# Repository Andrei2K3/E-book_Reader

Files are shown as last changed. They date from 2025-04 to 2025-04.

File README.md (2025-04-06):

# OpenBook Project - README

This repository contains the hardware, manufacturing, mechanical, and documentation files for **OpenBook**, a low-cost, open-source e-book reader built around the **ESP32-C6** microcontroller.

---

## Overview

The OpenBook is a low-power, open-source e-book reader designed around the ESP32-C6 microcontroller. Featuring Wi-Fi 6 and Bluetooth LE, it uses a large 7.5-inch e-paper display to achieve excellent readability and battery performance.

This document includes the system block diagram, hardware pinout, BOM, component links, design log, and licensing.

---

## System Block Diagram

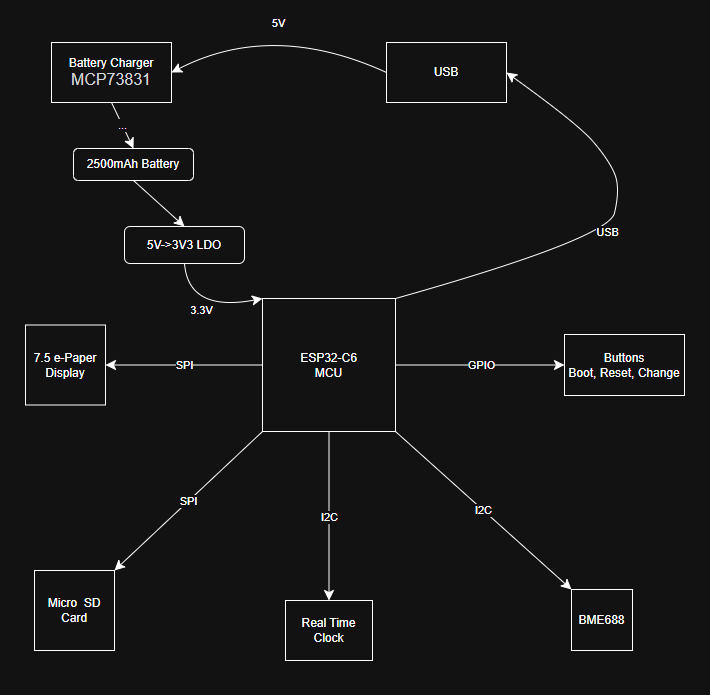
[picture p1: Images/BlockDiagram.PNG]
title


---

## Bill of Materials (BOM)

| Name of component | Device | Check Prices | DataSheet |
|---|---|---|---|
| U1 | W25Q512JVEIQ | https://www.snapeda.com/parts/W25Q512JVEIQ/Winbond+Electronics/view-part/?ref=eda | https://www.snapeda.com/parts/W25Q512JVEIQ/Winbond+Electronics/view-part/?ref=eda |
| U2 | ESP32-C6-WROOM-1-N8 | https://www.snapeda.com/parts/ESP32-C6-WROOM-1-N8/Espressif+Systems/view-part/?ref=eda | https://www.snapeda.com/parts/ESP32-C6-WROOM-1-N8/Espressif+Systems/view-part/?ref=eda |
| U3 | DS3231SN# | https://www.snapeda.com/parts/DS3231SN%23/Analog+Devices/view-part/?ref=eda | https://www.snapeda.com/parts/DS3231SN%23/Analog+Devices/view-part/?ref=eda |
| U4 | MAX17048G+T10 | https://www.snapeda.com/parts/MAX17048G+T10/Analog+Devices/view-part/?ref=eda | https://www.snapeda.com/parts/MAX17048G+T10/Analog+Devices/view-part/?ref=eda |
| U5 | ESP32_WROVER_SPARKFUN-IC-POWER_MCP73831 | https://eu.mouser.com/ProductDetail/Microchip-Technology/MCP73831T-2ACI-OT?qs=yUQqVecv4qvbBQBGbHx0Mw%3D%3Dcf | https://eu.mouser.com/ProductDetail/Microchip-Technology/MCP73831T-2ACI-OT?qs=yUQqVecv4qvbBQBGbHx0Mw%3D%3Dcf |
| BOOT_BUTTON | BUTTON_CUSYOMV1 | https://industry.panasonic.com/global/en/products/control/switch/light-touch/number/evqpuj02k | https://industry.panasonic.com/global/en/products/control/switch/light-touch/number/evqpuj02k |
| CHANGE_BUTTON | BUTTON_CUSYOMV1 | https://industry.panasonic.com/global/en/products/control/switch-light-touch/number/evqpuj02k | https://industry.panasonic.com/global/en/products/control/switch-light-touch/number/evqpuj02k |
| RESET_BUTTON | BUTTON_CUSYOMV1 | https://industry.panasonic.com/global/en/products/control/switch/light-touch/number/evqpuj02k | https://industry.panasonic.com/global/en/products/control/switch/light-touch/number/evqpuj02k |
| Q1 | ESP32_WROVER_SPARKFUN-DISCRETESEMI_MOSFET_...| https://componentsearchengine.com/part-view/DMG2305UX-7/Diodes%20Incorporated | https://componentsearchengine.com/part-view/DMG2305UX-7/Diodes%20Incorporated |
| Q2 | ESP32_WROVER_SPARKFUN-DISCRETESEMI_MOSFET_...| https://componentsearchengine.com/part-view/DMG2305UX-7/Diodes%20Incorporated | https://componentsearchengine.com/part-view/DMG2305UX-7/Diodes%20Incorporated |
| Q3 | D8 | https://componentsearchengine.com/part-view/SI1308EDL-T1-GE3/Vishay | https://componentsearchengine.com/part-view/SI1308EDL-T1-GE3/Vishay |
| PFMF.050.1 | ESP32C6_VARISTORCN1812 | https://www.mouser.co.uk/ProductDetail/EPCOS-TDK/B72520T0350K062?qs=dEfas%2FXlABIszF52uu7vrg%3D%3D | https://www.mouser.co.uk/ProductDetail/EPCOS-TDK/B72520T0350K062?qs=dEfas%2FXlABIszF52uu7vrg%3D%3D |
| IC1 | BD5229G-TR | https://componentsearchengine.com/part-view/BD5229G-TR/ROHM%20Semiconductor | https://componentsearchengine.com/part-view/BD5229G-TR/ROHM%20Semiconductor |
| IC4 | XC6220A331MR-G | https://componentsearchengine.com/part-view/XC6220A331MR-G/Torex | https://componentsearchengine.com/part-view/XC6220A331MR-G/Torex |
| J1 | FH34SRJ-24S-0.5SH_99_ | https://componentsearchengine.com/part-view/XC6220A331MR-G/Torex | https://componentsearchengine.com/part-view/XC6220A331MR-G/Torex |
| J2 | SAMACSYS_PARTS_USB4110-GF-A | https://componentsearchengine.com/part-view/USB4110-GF-A/GCT%20(GLOBAL%20CONNECTOR%20TECHNOLOGY | https://componentsearchengine.com/part-view/USB4110-GF-A/GCT%20(GLOBAL%20CONNECTOR%20TECHNOLOGY |
| J3 | QWIIC_CONNECTORJS-1MM | https://componentsearchengine.com/part-view/USB4110-GF-A/GCT%20(GLOBAL%20CONNECTOR%20TECHNOLOGY | https://componentsearchengine.com/part-view/USB4110-GF-A/GCT%20(GLOBAL%20CONNECTOR%20TECHNOLOGY |
| J4 | 112A-TAAR-R03_ATTEND | https://store.comet.srl.ro/Catalogue/Product/43497/ | https://store.comet.srl.ro/Catalogue/Product/43497/ |
| L1 | 744043680IND_4828-WE-TPC_WRE | https://eu.mouser.com/ProductDetail/Wurth-Elektronik/744043680?qs=PGXP4M47uW6VkZq%252BkzjrHA%3D%3D | https://eu.mouser.com/ProductDetail/Wurth-Elektronik/744043680?qs=PGXP4M47uW6VkZq%252BkzjrHA%3D%3D |
| SENSOR2 | ESP32_WROVER_BME680_BME680 | https://www.snapeda.com/parts/BME680/Bosch/view-part/?welcome=home | https://www.snapeda.com/parts/BME680/Bosch/view-part/?welcome=home |
| SJ1 | SJ | https://grabcad.com/library/solder-jumpers-1 | https://grabcad.com/library/solder-jumpers-1 |
| C1 | ESP32_WROVER_EAGLE-LTSPICE_CC0402 | https://industry.panasonic.com/global/en/products/control/switch/light-touch/number/evqpuj02k | https://industry.panasonic.com/global/en/products/control/switch/light-touch/number/evqpuj02k |
| C1_BAT | ESP32_WROVER_EAGLE-LTSPICE_CC0402 | https://industry.panasonic.com/global/en/products/control/switch/light-touch/number/evqpuj02k | https://industry.panasonic.com/global/en/products/control/switch/light-touch/number/evqpuj02k |
| C1_BAT1 | EAGLE-LTSPICE_CC0402 | https://industry.panasonic.com/global/en/products/control/switch/light-touch/number/evqpuj02k | https://industry.panasonic.com/global/en/products/control/switch/light-touch/number/evqpuj02k |
| C1_BAT2 | EAGLE-LTSPICE_CC0402 | https://industry.panasonic.com/global/en/products/control/switch/light-touch/number/evqpuj02k | https://industry.panasonic.com/global/en/products/control/switch/light-touch/number/evqpuj02k |
| C2 | ESP32_WROVER_EAGLE-LTSPICE_CC0402 | https://industry.panasonic.com/global/en/products/control/switch/light-touch/number/evqpuj02k | https://industry.panasonic.com/global/en/products/control/switch/light-touch/number/evqpuj02k |
| C2_BAT\ | ESP32_WROVER_EAGLE-LTSPICE_CC0402 | https://industry.panasonic.com/global/en/products/control/switch/light-touch/number/evqpuj02k | https://industry.panasonic.com/global/en/products/control/switch/light-touch/number/evqpuj02k |
| C3 | RCL_CPOL-EUCT3528 | https://industry.panasonic.com/global/en/products/control/switch/light-touch/number/evqpuj02k | https://industry.panasonic.com/global/en/products/control/switch/light-touch/number/evqpuj02k |
| C4 | ESP32_WROVER_EAGLE-LTSPICE_CC0402 | https://industry.panasonic.com/global/en/products/control/switch/light-touch/number/evqpuj02k | https://industry.panasonic.com/global/en/products/control/switch/light-touch/number/evqpuj02k |
| C4_USB | ESP32_WROVER_EAGLE-LTSPICE_CC0402 | https://industry.panasonic.com/global/en/products/control/switch/light-touch/number/evqpuj02k | https://industry.panasonic.com/global/en/products/control/switch/light-touch/number/evqpuj02k |
| C5 | ESP32_WROVER_EAGLE-LTSPICE_CC0402 | https://industry.panasonic.com/global/en/products/control/switch/light-touch/number/evqpuj02k | https://industry.panasonic.com/global/en/products/control/switch/light-touch/number/evqpuj02k |
| C5_USB | ESP32_WROVER_EAGLE-LTSPICE_CC0402 | https://industry.panasonic.com/global/en/products/control/switch/light-touch/number/evqpuj02k | https://industry.panasonic.com/global/en/products/control/switch/light-touch/number/evqpuj02k |
| C6 | ESP32_WROVER_EAGLE-LTSPICE_CC0402 | https://industry.panasonic.com/global/en/products/control/switch/light-touch/number/evqpuj02k | https://industry.panasonic.com/global/en/products/control/switch/light-touch/number/evqpuj02k |
| C7 | ESP32_WROVER_EAGLE-LTSPICE_CC0402 | https://industry.panasonic.com/global/en/products/control/switch/light-touch/number/evqpuj02k | https://industry.panasonic.com/global/en/products/control/switch/light-touch/number/evqpuj02k |
| C8 | ESP32_WROVER_EAGLE-LTSPICE_CC0402 | https://industry.panasonic.com/global/en/products/control/switch/light-touch/number/evqpuj02k | https://industry.panasonic.com/global/en/products/control/switch/light-touch/number/evqpuj02k |
| C9 | EAGLE-LTSPICE_CC0402 | https://industry.panasonic.com/global/en/products/control/switch/light-touch/number/evqpuj02k | https://industry.panasonic.com/global/en/products/control/switch/light-touch/number/evqpuj02k |
| C10 | ESP32_WROVER_EAGLE-LTSPICE_CC0402 | https://industry.panasonic.com/global/en/products/control/switch/light-touch/number/evqpuj02k | https://industry.panasonic.com/global/en/products/control/switch/light-touch/number/evqpuj02k |
| C10_SUPERCAP | CPH3225A | https://www.snapeda.com/parts/CPH3225A/Seiko+Instruments/view-part/?ref=eda | https://www.snapeda.com/parts/CPH3225A/Seiko+Instruments/view-part/?ref=eda |
| CHG_LED | ADAFRUIT_LEDCHIP-LED0603 | https://www.snapeda.com/parts/KP-1608SURCK/Kingbright/view-part/?ref=search&t=LED%200603 | https://www.snapeda.com/parts/KP-1608SURCK/Kingbright/view-part/?ref=search&t=LED%200603 |
| C_DELAY | ESP32_WROVER_EAGLE-LTSPICE_CC0402 | https://industry.panasonic.com/global/en/products/control/switch/light-touch/number/evqpuj02k | https://industry.panasonic.com/global/en/products/control/switch/light-touch/number/evqpuj02k |
| D1 | USBLC6-2SC6Y | https://www.snapeda.com/parts/USBLC6-2SC6Y/STMicroelectronics/view-part/?ref=eda | https://www.snapeda.com/parts/USBLC6-2SC6Y/STMicroelectronics/view-part/?ref=eda |
| D2 | ESP32_WROVER_AVX---SD0805S020S1R0_AVX_... | https://eu.mouser.com/ProductDetail/KYOCERA-AVX/SD0805S020S1R0?qs=jCA%252BPfw4LHbpkAoSnwrdjw%3D%3D | http://datasheets.avx.com/schottky.pdf |
| D3 | MBR0530 | https://eu.mouser.com/ProductDetail/KYOCERA-AVX/SD0805S020S1R0?qs=jCA%252BPfw4LHbpkAoSnwrdjw%3D%3D | https://eu.mouser.com/ProductDetail/KYOCERA-AVX/SD0805S020S1R0?qs=jCA%252BPfw4LHbpkAoSnwrdjw%3D%3D |
| D4 | MBR0530 | https://www.snapeda.com/parts/MBR0530/Onsemi/view-part/?ref=eda | https://www.snapeda.com/parts/MBR0530/Onsemi/view-part/?ref=eda |
| D5 | MBR0530 | https://www.snapeda.com/parts/MBR0530/Onsemi/view-part/?ref=eda | https://www.snapeda.com/parts/MBR0530/Onsemi/view-part/?ref=eda |
| D6 | PGB1010603MR | https://www.snapeda.com/parts/PGB1010603MR/Littelfuse/view-part/?ref=eda | https://www.snapeda.com/parts/PGB1010603MR/Littelfuse/view-part/?ref=eda |
| D7 | ESP32_WROVER_AVX---SD0805S020S1R0_AVX_... | https://eu.mouser.com/ProductDetail/KYOCERA-AVX/SD0805S020S1R0?qs=jCA%252BPfw4LHbpkAoSnwrdjw%3D%3D | http://datasheets.avx.com/schottky.pdf |
| D8 | PGB1010603MR | https://www.snapeda.com/parts/PGB1010603MR/Littelfuse/view-part/?ref=eda | https://www.snapeda.com/parts/PGB1010603MR/Littelfuse/view-part/?ref=eda |
| D9 | PGB1010603MR | https://www.snapeda.com/parts/PGB1010603MR/Littelfuse/view-part/?ref=eda | https://www.snapeda.com/parts/PGB1010603MR/Littelfuse/view-part/?ref=eda |
| D10 | PGB1010603MR | https://www.snapeda.com/parts/PGB1010603MR/Littelfuse/view-part/?ref=eda | https://www.snapeda.com/parts/PGB1010603MR/Littelfuse/view-part/?ref=eda |
| D11 | PGB1010603MR | https://www.snapeda.com/parts/PGB1010603MR/Littelfuse/view-part/?ref=eda | https://www.snapeda.com/parts/PGB1010603MR/Littelfuse/view-part/?ref=eda |
| D12 | PGB1010603MR | https://www.snapeda.com/parts/PGB1010603MR/Littelfuse/view-part/?ref=eda | https://www.snapeda.com/parts/PGB1010603MR/Littelfuse/view-part/?ref=eda |
| EPD_C1 | ESP32_WROVER_EAGLE-LTSPICE_CC0402 | https://industry.panasonic.com/global/en/products/control/switch/light-touch/number/evqpuj02k | https://industry.panasonic.com/global/en/products/control/switch/light-touch/number/evqpuj02k |
| EPD_C2 | ESP32_WROVER_EAGLE-LTSPICE_CC0402 | https://industry.panasonic.com/global/en/products/control/switch/light-touch/number/evqpuj02k | https://industry.panasonic.com/global/en/products/control/switch/light-touch/number/evqpuj02k |
| EPD_C5 | ESP32_WROVER_EAGLE-LTSPICE_CC0402 | https://industry.panasonic.com/global/en/products/control/switch/light-touch/number/evqpuj02k | https://industry.panasonic.com/global/en/products/control/switch/light-touch/number/evqpuj02k |
| EPD_C6 | ESP32_WROVER_EAGLE-LTSPICE_CC0402 | https://industry.panasonic.com/global/en/products/control/switch/light-touch/number/evqpuj02k | https://industry.panasonic.com/global/en/products/control/switch/light-touch/number/evqpuj02k |
| EPD_C7 | ESP32_WROVER_EAGLE-LTSPICE_CC0402 | https://industry.panasonic.com/global/en/products/control/switch/light-touch/number/evqpuj02k | https://industry.panasonic.com/global/en/products/control/switch/light-touch/number/evqpuj02k |
| EPD_C8 | ESP32_WROVER_EAGLE-LTSPICE_CC0402 | https://industry.panasonic.com/global/en/products/control/switch/light-touch/number/evqpuj02k | https://industry.panasonic.com/global/en/products/control/switch/light-touch/number/evqpuj02k |
| EPD_C9 | ESP32_WROVER_EAGLE-LTSPICE_CC0402 | https://industry.panasonic.com/global/en/products/control/switch/light-touch/number/evqpuj02k | https://industry.panasonic.com/global/en/products/control/switch/light-touch/number/evqpuj02k |
| EPD_C10 | ESP32_WROVER_EAGLE-LTSPICE_CC0402 | https://industry.panasonic.com/global/en/products/control/switch/light-touch/number/evqpuj02k | https://industry.panasonic.com/global/en/products/control/switch/light-touch/number/evqpuj02k |
| EPD_C11 | ESP32_WROVER_EAGLE-LTSPICE_CC0402 | https://industry.panasonic.com/global/en/products/control/switch/light-touch/number/evqpuj02k | https://industry.panasonic.com/global/en/products/control/switch/light-touch/number/evqpuj02k |
| EPD_C12 | ESP32_WROVER_EAGLE-LTSPICE_CC0402 | https://industry.panasonic.com/global/en/products/control/switch/light-touch/number/evqpuj02k | https://industry.panasonic.com/global/en/products/control/switch/light-touch/number/evqpuj02k |
| R1 | ESP32_WROVER_EAGLE-LTSPICE_RR0402 | https://componentsearchengine.com/part-view/R0402%201%25%20100%20K%20(RC0402FR-07100KL | https://componentsearchengine.com/part-view/R0402%201%25%20100%20K%20(RC0402FR-07100KL |
| R1-PINH | ESP32_WROVER_EAGLE-LTSPICE_RR0402 | https://componentsearchengine.com/part-view/R0402%201%25%20100%20K%20(RC0402FR-07100KL | https://componentsearchengine.com/part-view/R0402%201%25%20100%20K%20(RC0402FR-07100KL |
| R1-PINH1 | ESP32_WROVER_EAGLE-LTSPICE_RR0402 | https://componentsearchengine.com/part-view/R0402%201%25%20100%20K%20(RC0402FR-07100KL | https://componentsearchengine.com/part-view/R0402%201%25%20100%20K%20(RC0402FR-07100KL |
| R1_BAT | ESP32_WROVER_EAGLE-LTSPICE_RR0402 | https://componentsearchengine.com/part-view/R0402%201%25%20100%20K%20(RC0402FR-07100KL | https://componentsearchengine.com/part-view/R0402%201%25%20100%20K%20(RC0402FR-07100KL |
| R1_PWRUSB | ESP32_WROVER_EAGLE-LTSPICE_RR0402 | https://componentsearchengine.com/part-view/R0402%201%25%20100%20K%20(RC0402FR-07100KL | https://componentsearchengine.com/part-view/R0402%201%25%20100%20K%20(RC0402FR-07100KL |
| R2 | ESP32_WROVER_EAGLE-LTSPICE_RR0402 | https://componentsearchengine.com/part-view/R0402%201%25%20100%20K%20(RC0402FR-07100KL | https://componentsearchengine.com/part-view/R0402%201%25%20100%20K%20(RC0402FR-07100KL |
| R2-PINH | ESP32_WROVER_EAGLE-LTSPICE_RR0402 | https://componentsearchengine.com/part-view/R0402%201%25%20100%20K%20(RC0402FR-07100KL | https://componentsearchengine.com/part-view/R0402%201%25%20100%20K%20(RC0402FR-07100KL |
| R2-PINH1 | ESP32_WROVER_EAGLE-LTSPICE_RR0402 | https://componentsearchengine.com/part-view/R0402%201%25%20100%20K%20(RC0402FR-07100KL | https://componentsearchengine.com/part-view/R0402%201%25%20100%20K%20(RC0402FR-07100KL |
| R2-USB | ESP32_WROVER_EAGLE-LTSPICE_RR0402 | https://componentsearchengine.com/part-view/R0402%201%25%20100%20K%20(RC0402FR-07100KL | https://componentsearchengine.com/part-view/R0402%201%25%20100%20K%20(RC0402FR-07100KL |
| R2-USB1 | ESP32_WROVER_EAGLE-LTSPICE_RR0402 | https://componentsearchengine.com/part-view/R0402%201%25%20100%20K%20(RC0402FR-07100KL | https://componentsearchengine.com/part-view/R0402%201%25%20100%20K%20(RC0402FR-07100KL |
| R2_BAT | ESP32_WROVER_EAGLE-LTSPICE_RR0402 | https://componentsearchengine.com/part-view/R0402%201%25%20100%20K%20(RC0402FR-07100KL | https://componentsearchengine.com/part-view/R0402%201%25%20100%20K%20(RC0402FR-07100KL |
| R3 | ESP32_WROVER_EAGLE-LTSPICE_RR0402 | https://componentsearchengine.com/part-view/R0402%201%25%20100%20K%20(RC0402FR-07100KL | https://componentsearchengine.com/part-view/R0402%201%25%20100%20K%20(RC0402FR-07100KL |
| R4 | ESP32_WROVER_EAGLE-LTSPICE_RR0402 | https://componentsearchengine.com/part-view/R0402%201%25%20100%20K%20(RC0402FR-07100KL | https://componentsearchengine.com/part-view/R0402%201%25%20100%20K%20(RC0402FR-07100KL |
| R5 | ESP32_WROVER_EAGLE-LTSPICE_RR0402 | https://componentsearchengine.com/part-view/R0402%201%25%20100%20K%20(RC0402FR-07100KL | https://componentsearchengine.com/part-view/R0402%201%25%20100%20K%20(RC0402FR-07100KL |
| R6 | ESP32_WROVER_EAGLE-LTSPICE_RR0402 | https://componentsearchengine.com/part-view/R0402%201%25%20100%20K%20(RC0402FR-07100KL | https://componentsearchengine.com/part-view/R0402%201%25%20100%20K%20(RC0402FR-07100KL |
| R7 | ESP32_WROVER_EAGLE-LTSPICE_RR0402 | https://componentsearchengine.com/part-view/R0402%201%25%20100%20K%20(RC0402FR-07100KL | https://componentsearchengine.com/part-view/R0402%201%25%20100%20K%20(RC0402FR-07100KL |
| R8 | ESP32_WROVER_EAGLE-LTSPICE_RR0402 | https://componentsearchengine.com/part-view/R0402%201%25%20100%20K%20(RC0402FR-07100KL | https://componentsearchengine.com/part-view/R0402%201%25%20100%20K%20(RC0402FR-07100KL |
| R9 | ESP32_WROVER_EAGLE-LTSPICE_RR0402 | https://componentsearchengine.com/part-view/R0402%201%25%20100%20K%20(RC0402FR-07100KL | https://componentsearchengine.com/part-view/R0402%201%25%20100%20K%20(RC0402FR-07100KL |
| R10 | ESP32_WROVER_EAGLE-LTSPICE_RR0402 | https://componentsearchengine.com/part-view/R0402%201%25%20100%20K%20(RC0402FR-07100KL | https://componentsearchengine.com/part-view/R0402%201%25%20100%20K%20(RC0402FR-07100KL |
| R_BOOT | ESP32_WROVER_EAGLE-LTSPICE_RR0402 | https://componentsearchengine.com/part-view/R0402%201%25%20100%20K%20(RC0402FR-07100KL | https://componentsearchengine.com/part-view/R0402%201%25%20100%20K%20(RC0402FR-07100KL |
| R_CAPACITOR | ESP32_WROVER_EAGLE-LTSPICE_RR0402 | https://componentsearchengine.com/part-view/R0402%201%25%20100%20K%20(RC0402FR-07100KL | https://componentsearchengine.com/part-view/R0402%201%25%20100%20K%20(RC0402FR-07100KL |
| R_CHANGE | ESP32_WROVER_EAGLE-LTSPICE_RR0402 | https://componentsearchengine.com/part-view/R0402%201%25%20100%20K%20(RC0402FR-07100KL | https://componentsearchengine.com/part-view/R0402%201%25%20100%20K%20(RC0402FR-07100KL |
| R_CL1 | ESP32_WROVER_EAGLE-LTSPICE_RR0402 | https://componentsearchengine.com/part-view/R0402%201%25%20100%20K%20(RC0402FR-07100KL | https://componentsearchengine.com/part-view/R0402%201%25%20100%20K%20(RC0402FR-07100KL |
| R_RESET | ESP32_WROVER_EAGLE-LTSPICE_RR0402 | https://componentsearchengine.com/part-view/R0402%201%25%20100%20K%20(RC0402FR-07100KL | https://componentsearchengine.com/part-view/R0402%201%25%20100%20K%20(RC0402FR-07100KL |
| TP1 | TPTP20R | - | - |
| TP2 | TPTP20R | - | - |
| TP3 | TPTP20R | - | - |
| TP4 | TPTP20R | - | - |
| TP5 | TPTP20R | - | - |
| TP6 | TPTP20R | - | - |
| TP7 | TPTP20R | - | - |
| TP8 | TPTP20R | - | - |
| TP9 | TPTP20R | - | - |
| TP10 | TPTP20R | - | - |
| TP11 | TPTP20R | - | - |
| TP12 | TPTP20R | - | - |
| TP13 | TPTP20R | - | - |
| TP14 | TPTP20R | - | - |
| TP15 | TPTP20R | - | - |
| TP16 | TPTP20R | - | - |
| TP17 | TPTP20R | - | - |

---

## Main Hardware Components

# ESP32-C6 Microcontroller

- Architecture: 32-bit RISC-V core operating up to 160 MHz
- Communication: Built-in Wi-Fi 6, Bluetooth 5 LE, and USB 2.0 interface
- RAM & Storage: 512KB SRAM onboard, paired with 8MB external flash
- Power Efficiency: Equipped with advanced low-power and sleep modes
- I/O Capabilities: Supports SPI, I²C, UART, and multiple GPIOs

# SD Card Slot

- Storage Role: Enables additional memory for e-books, logs, and firmware
- Interface Options: Compatible with both SPI and native SD protocols

# External Memory

- Type: Serial NOR Flash, model W25Q512JVEIQ
- Capacity: Provides 8MB for firmware storage and high-volume data

# E-Paper Display

- Dimensions & Quality: 7.5-inch diagonal, 800×480 resolution
- Energy Profile: Consumes power only during updates; remains static otherwise
- Data Transfer: Communicates using a 4-wire SPI interface

# USB-C Interface

- Primary Roles: Allows battery charging, data transfer, and firmware updates
- Electrical Safety: Integrated ESD protection and compliant terminations
- Update Support: Enables both USB-based and OTA software upgrades

# Power Management

- Energy Source: Uses a 2500mAh 3.7V Li-Po rechargeable battery
- Monitoring Features: Battery state tracked via MAX17048 fuel gauge (I²C)
- Charging Circuitry: Based on MCP73831 controller via USB-C input
- Voltage Regulation: Supplies a clean 3.3V rail using an LDO such as XC6220

# Environmental Sensor

- Sensor Type: BME688 integrated environmental sensor
- Measured Parameters: Ambient temperature, relative humidity, atmospheric pressure, and air quality (VOC/eCO2)
- Communication: I²C protocol at 400kHz

# Input Controls

- Functional Use: Facilitates navigation, menu interaction, and device reset

---

## Communication Interfaces Overview

# USB

- Provides both power input and data communication via the USB-C port.
- Supports firmware flashing and charging through a single interface.

# I²C Bus

- Used to interface with low-speed peripherals such as:
    - Environmental sensor (BME688)
    - Battery monitoring chip (MAX17048)
    - RT Clock (DS3231)
    - Qwiic-compatible expansion modules

# General Purpose I/O (GPIO)

- Dedicated digital inputs for tactile button controls (3x)
- Additional control signals for peripherals, such as:
    - Display reset
    - E-paper busy status monitoring
    - Power control or wake signals

# SPI Interface

- Standard 4-wire SPI used for driving the e-paper display

---

## Estimated Power Consumption

This section provides an overview of the average power consumption for each hardware component in the OpenBook E-Reader during both active use and sleep modes.

| Component | Active Mode Consumption | Sleep / Idle Consumption | Notes |
|---|---|---|---|
| **ESP32-C6 MCU** | 80–150 mA | < 50 µA (deep sleep) | Includes Wi-Fi processing and peripheral control |
| **7.5” E-Paper Display** | ~30–40 mA (during refresh) | ~1 µA (static image retained) | Power only consumed during screen updates |
| **BME688 Sensor** | ~2.1 mA | < 1 µA (standby mode) | Used for environmental data collection (temp/humidity/air quality) |
| **DS3231 RTC** | — | ~2 µA | Always running to keep accurate time |
| **MAX17048 Fuel Gauge** | ~50 µA | ~50 µA | Monitors battery level continuously |
| **MCP73831 Charging IC** | Up to 1A (when charging) | 0 µA (when idle) | Controlled via USB VBUS connection |
| **Buttons (3x)** | 0 mA (passive) | 0 mA | Use GPIO input pull-downs; no active consumption |
| **SD Card (optional)** | 10–30 mA (read/write) | 0 mA (unmounted) | Used only during eBook loading or logging |
| **USB Peripherals** | Varies (USB Host mode) | 0 mA | Only active when data transfer is in use |

### Total Estimated Consumption

| Usage Scenario | Estimated Total Current |
|---|---|
| **Full Active Reading** | ~120–170 mA |
| **Wi-Fi + Sensor Polling** | ~100–130 mA |
| **Partial Sleep (Wi-Fi Off)**| ~5–10 mA |
| **Deep Sleep (RTC only)** | ~100–150 µA |

### Battery Life Estimation

Given a 2500 mAh 3.7V Li-Po battery:

- **Active Reading 2 hours/day** → ~7–10 days battery life
- **Standby Mode Only** → up to **1 month**
- **Mixed Use (Wi-Fi, sensors, display refreshes)** → 5–7 days typical

These values are estimations and will vary depending on usage patterns, Wi-Fi activity, and environmental sensor polling intervals.

---

## ESP32-C6 Pin Mapping

This table shows the actual GPIO-to-function mapping as used in the OpenBook E-Reader, based on the schematic of the ESP32-C6-WROOM-1-N8 module provided.

| GPIO | Label in Schematic | Function Description | Peripheral / Role |
|---|---|---|---|
| **GPIO9** | IO0 / BOOT | Boot select button | Used for entering UART download mode |
| **GPIO4** | SS_SD | SPI Chip Select for SD card | microSD card |
| **GPIO6** | SCK | SPI Clock | Shared SPI (e-Paper + SD) |
| **GPIO7** | MOSI | SPI Data Out | Shared SPI (e-Paper + SD) |
| **GPIO2** | MISO | SPI Data In | SD card only |
| **GPIO5** | EPD_DC | Data/Command pin for e-paper display | e-Paper display |
| **GPIO10** | EPD_CS | Chip Select for e-paper display | e-Paper display |
| **GPIO3** | EPD_BUSY | Busy pin input from e-paper display | e-Paper display |
| **GPIO11** | FLASH_CS | Flash chip select (internal flash) | Reserved – do not use externally |
| **GPIO13**| USB D+ | USB 2.0 Full Speed Data+ | USB-C Interface |
| **GPIO12**| USB D- | USB 2.0 Full Speed Data- | USB-C Interface |
| **GPIO16**| TX | UART TX (console/debug) | Optional serial logging |
| **GPIO17**| RX | UART RX (console/debug) | Optional serial logging |
| **GPIO18**| RTC_RST | RTC reset | DS3231 (RTC) |
| **GPIO0**| INT_RTC | RTC interrupt/alarm | DS3231 optional alarm/interrupt |
| **GPIO21**| SDA | I2C Data Line | Shared between RTC, BME688, MAX17048 |
| **GPIO22**| SCL | I2C Clock Line | Shared between RTC, BME688, MAX17048 |
| **GPIO20**| EPD_3V3_C | Power control / enable for e-paper display  | Can be used for low-power control |
| **GPIO23**| EPD_RST | Redundant label for GPIO8 | See GPIO8 (same net) |

---

# PCB Design and Mechanical Integration

The OpenBook PCB has been designed as a compact, two-layer board with careful attention to power integrity, signal routing, and EMI minimization. Components are placed for thermal efficiency and optimal antenna performance.
- The /Hardware directory contains the original KiCad schematic (.sch) and PCB layout (.brd) files for further modification or inspection.
- High-quality 3D renderings of the PCB and complete device are available in the /Images folder.
- 3D models of the enclosure, including exploded views and Fusion 360 assemblies, can be found in /Mechanical.
- The /Manufacturing folder includes production-ready files such as Gerbers, BOM and Pick & Place data for automated assembly.

---

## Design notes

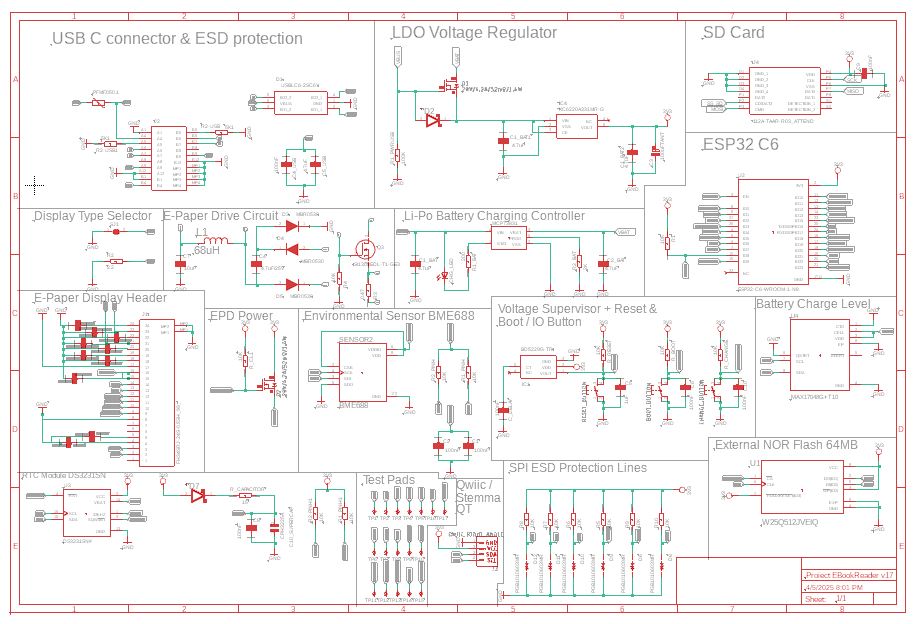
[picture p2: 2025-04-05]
Images/Schematic.JPG

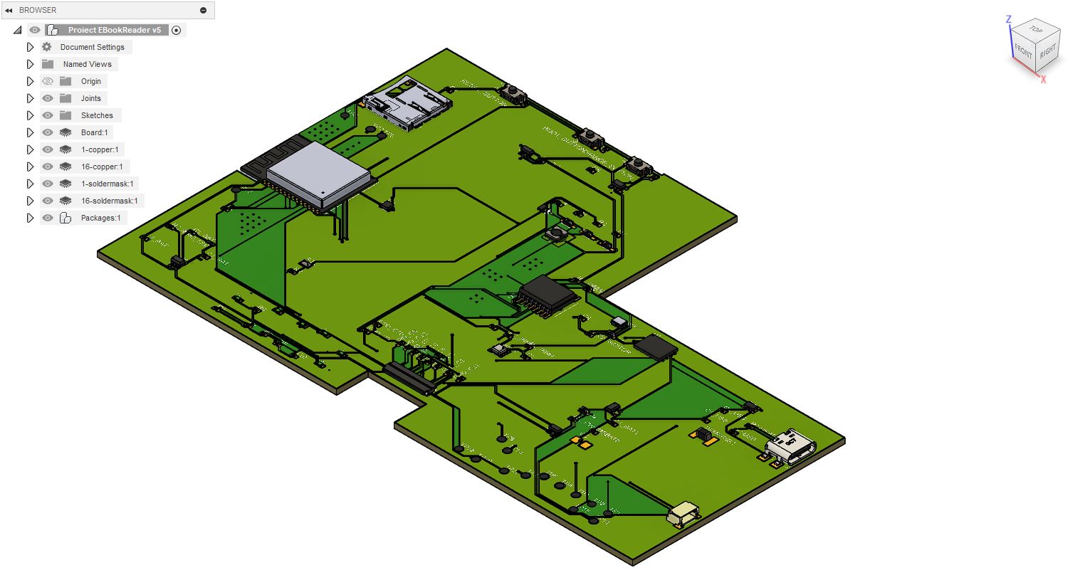
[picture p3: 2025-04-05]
Images/3d_Pcb.JPG

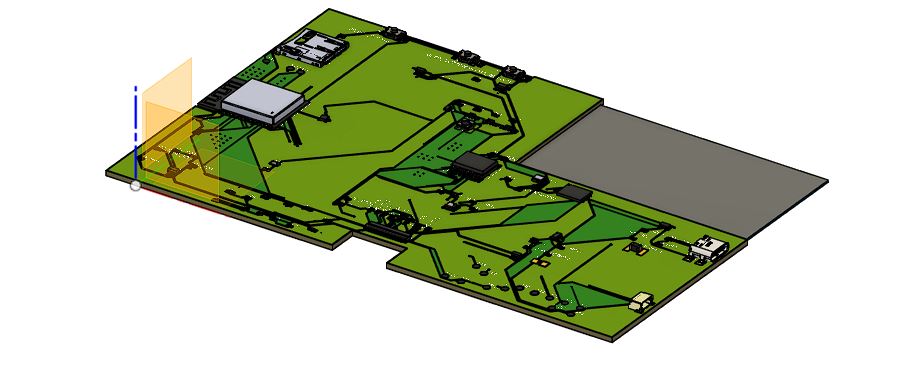
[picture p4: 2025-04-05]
Images/battery+3d_pcb.JPG

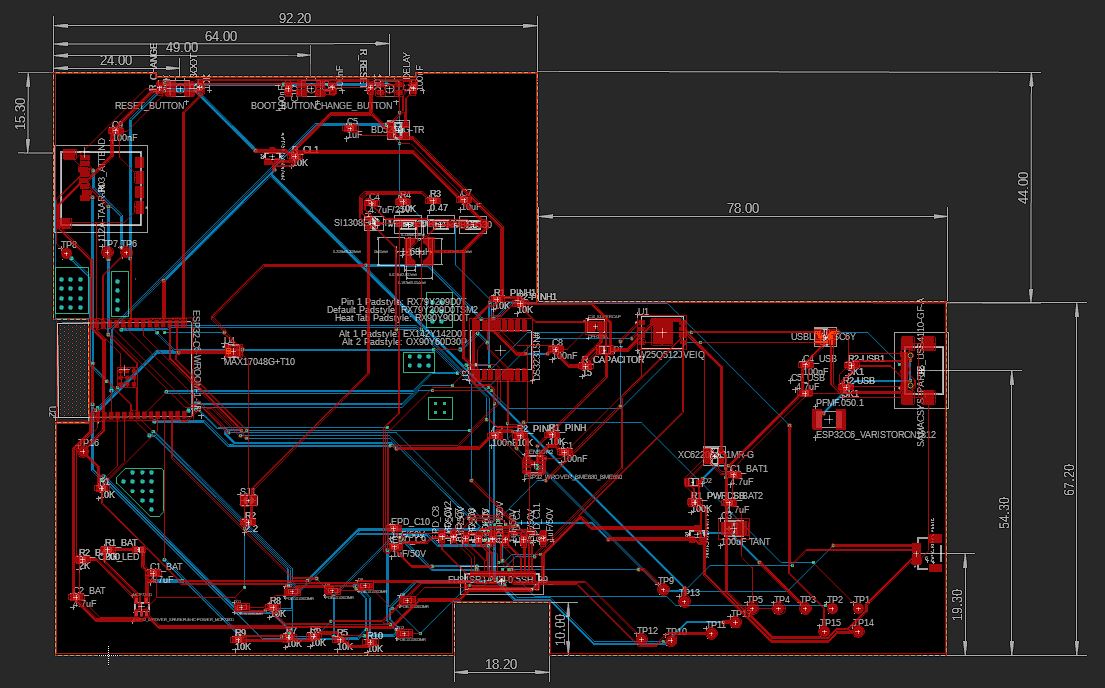
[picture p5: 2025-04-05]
Images/Pcb.JPG

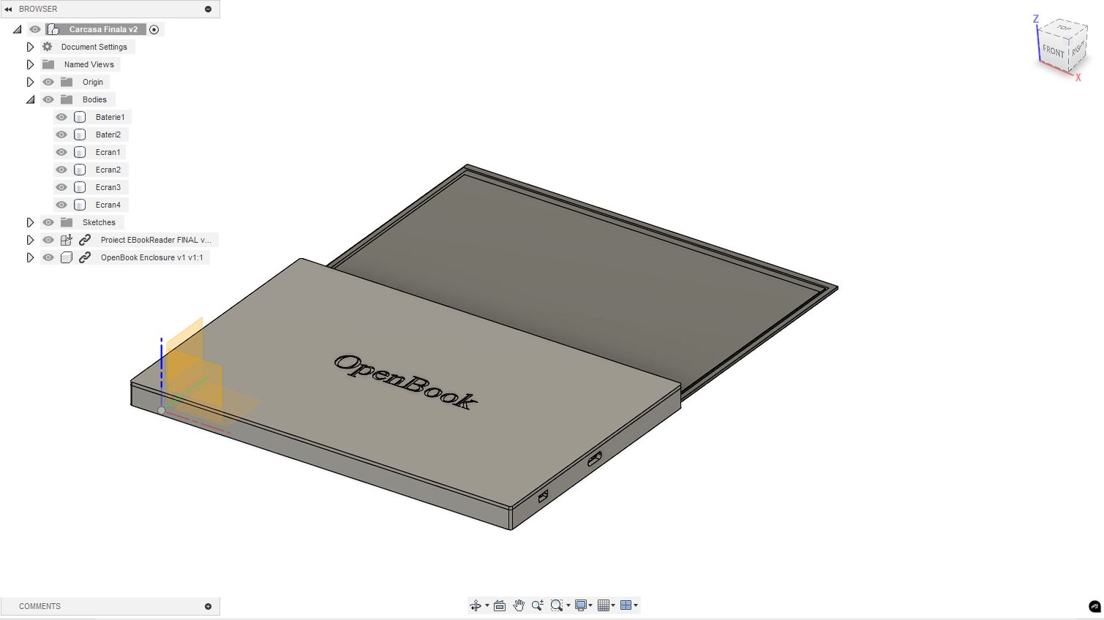
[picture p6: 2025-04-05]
Images/Full_Device.JPG

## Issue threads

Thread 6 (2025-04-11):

Erori Copper Width

DragosCojocaru9, 2025-04-11:
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

Sugestii de remediere:

- Selecteaza traseele din clasa 1 power si mareste-le latimea pentru a respecta regula DRC.
- Poti verifica in Design Manager → Net Classes → 1 power si ajusteaza Width la o valoare adecvata
- Reruteaza manual sau foloseste Change → Width si Ripup + Route pentru a modifica traseele existente.

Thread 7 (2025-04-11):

cpl file

DragosCojocaru9, 2025-04-11:
## Part: CHG_LED
- **Device**: ADAFRUIT_LEDCHIP-LED0603
- **PURCHASE-URL**: nu este
- **SNAPEDA_LINK**: nu este
- **DATASHEET**: nu este
---
## Part: SJ1
- **Device**: SJ
- **PURCHASE-URL**: nu este
- **SNAPEDA_LINK**: nu este
- **DATASHEET**: nu este
---
## Part: EPD_C5
- **Device**: EAGLE-LTSPICE_CC0402
- **PURCHASE-URL**: nu este
- **SNAPEDA_LINK**: nu este
- **DATASHEET**: nu este

Andrei2K3, 2025-04-14:
Nu am gasit la acestea cele necesare..

Closed 2025-04-14.

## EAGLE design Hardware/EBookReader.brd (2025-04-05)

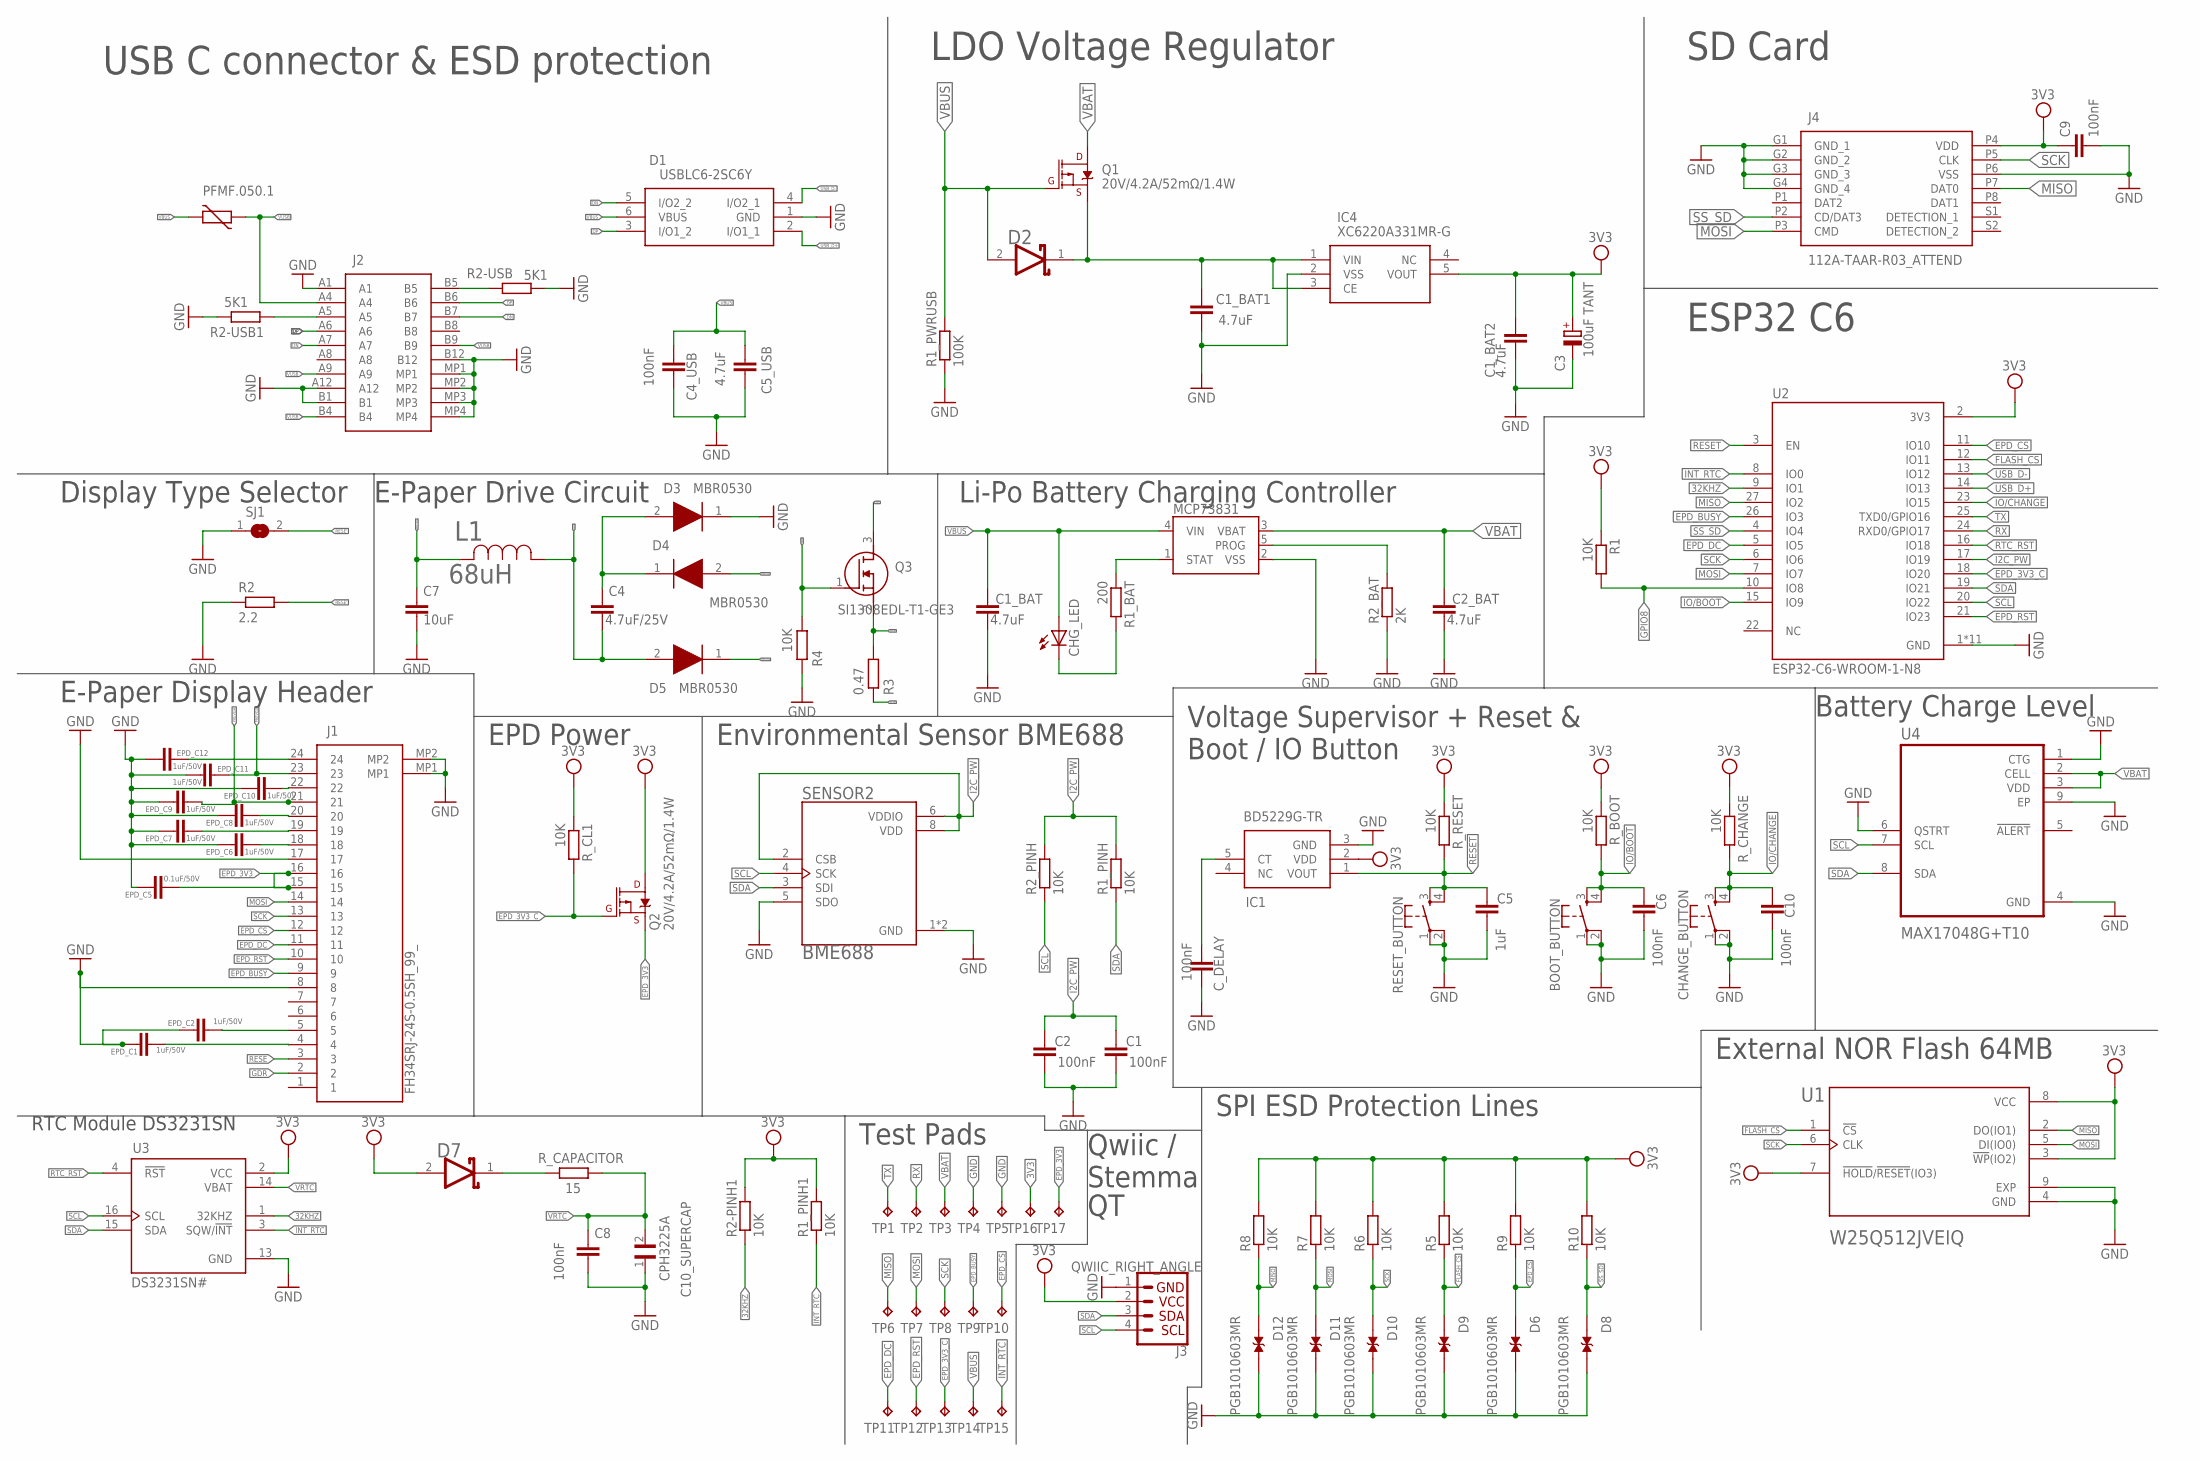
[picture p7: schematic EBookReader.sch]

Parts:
BOOT_BUTTON: BUTTON_CUSYOMV1; MYBUTTON
C1, C2, C4_USB, C6, C8, C9, C10: 100nF; EAGLE-LTSPICE_C0402
C1_BAT, C1_BAT1, C1_BAT2, C2_BAT, C5_USB: 4.7uF; EAGLE-LTSPICE_C0402
C3: 100uF TANT; RCL_CT3528
C4: 4.7uF/25V; EAGLE-LTSPICE_C0402
C5: 1uF; EAGLE-LTSPICE_C0402
C7: 10uF; EAGLE-LTSPICE_C0402
C10_SUPERCAP: CPH3225A; CAPCP3225X100N
CHANGE_BUTTON: BUTTON_CUSYOMV1; MYBUTTON
CHG_LED: ADAFRUIT_LEDCHIP-LED0603; ADAFRUIT_CHIP-LED0603
C_DELAY: 100nF; EAGLE-LTSPICE_C0402
D1: USBLC6-2SC6Y; SOT95P280X145-6N
D2, D7: ESP32_WROVER_AVX---SD0805S020S1R0_AVX_SD0805S020S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; ESP32_WROVER_AVX---SD0805S020S1R0_AVX_SD0805S020S1R0_0
D3, D4, D5: MBR0530; SOD3716X135N
D6, D8, D9, D10, D11, D12: PGB1010603MR; DIOC1608X36N
EPD_C1, EPD_C2, EPD_C6, EPD_C7, EPD_C8, EPD_C9, EPD_C10, EPD_C11, EPD_C12: 1uF/50V; EAGLE-LTSPICE_C0402
EPD_C5: 0.1uF/50V; EAGLE-LTSPICE_C0402
IC1: BD5229G-TR; SOT95P280X125-5N
IC4: XC6220A331MR-G; SOT95P280X120-5N
J1: FH34SRJ-24S-0.5SH_99_; FH34SRJ24S05SH99
J2: SAMACSYS_PARTS_USB4110-GF-A; SAMACSYS_PARTS_USB4110GFA
J3: QWIIC_RIGHT_ANGLE; JST04_1MM_RA
J4: 112A-TAAR-R03_ATTEND; 112ATAARR03ATTEND
L1: 68uH; IND_4828-WE-TPC_WRE
MCP73831: ESP32_WROVER_SPARKFUN-IC-POWER_MCP73831; ESP32_WROVER_SPARKFUN-IC-POWER_SOT23-5
PFMF.050.1: ESP32C6_VARISTORCN1812; ESP32C6_VARISTOR_CT/CN1812
Q1, Q2: 20V/4.2A/52mΩ/1.4W; ESP32_WROVER_SPARKFUN-DISCRETESEMI_SOT23-3
Q3: SI1308EDL-T1-GE3; SOT65P210X110-3N
R1, R1_PINH, R1_PINH1, R2-PINH1, R2_PINH, R4, R5, R6, R7, R8, R9, R10: 10K; ESP32_WROVER_EAGLE-LTSPICE_R0402
R1_BAT: 200; ESP32_WROVER_EAGLE-LTSPICE_R0402
R1_PWRUSB: 100K; ESP32_WROVER_EAGLE-LTSPICE_R0402
R2: 2.2; ESP32_WROVER_EAGLE-LTSPICE_R0402
R2-USB, R2-USB1: 5K1; ESP32_WROVER_EAGLE-LTSPICE_R0402
R2_BAT: 2K; ESP32_WROVER_EAGLE-LTSPICE_R0402
R3: 0.47; ESP32_WROVER_EAGLE-LTSPICE_R0402
RESET_BUTTON: BUTTON_CUSYOMV1; MYBUTTON
R_BOOT: 10K; ESP32_WROVER_EAGLE-LTSPICE_R0402
R_CAPACITOR: 15; ESP32_WROVER_EAGLE-LTSPICE_R0402
R_CHANGE: 10K; ESP32_WROVER_EAGLE-LTSPICE_R0402
R_CL1: 10K; ESP32_WROVER_EAGLE-LTSPICE_R0402
R_RESET: 10K; ESP32_WROVER_EAGLE-LTSPICE_R0402
SENSOR2: ESP32_WROVER_BME680_BME680; ESP32_WROVER_BME680_PSON80P300X300X100-8N
SJ1: SJ
TP1, TP2, TP3, TP4, TP5, TP6, TP7, TP8, TP9, TP10, TP11, TP12, TP13, TP14, TP15, TP16, TP17: TPTP20R; TP20R
U1: W25Q512JVEIQ; SON127P600X800X80-9N
U2: ESP32-C6-WROOM-1-N8; XCVR_ESP32-C6-WROOM-1-N8
U3: DS3231SN#; SOIC127P1032X265-16N
U4: MAX17048G+T10; SON50P200X200X80-9N

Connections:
3V3: C1_BAT2.1, C3.+, C9.1, D7.2 (ANODE), IC1.2 (VDD), IC4.5 (VOUT), J3.2, J4.P4 (VDD), Q2.3 (D), R1.1, R1_PINH1.2, R2-PINH1.2, R5.2, R6.2, R7.2, R8.2, R9.2, R10.2, R_BOOT.1, R_CHANGE.1, R_CL1.1, R_RESET.1, TP16.TP, U1.3 (!WP!(IO2)), U1.7 (!HOLD!/!RESET!(IO3)), U1.8 (VCC), U2.2 (3V3), U3.2 (VCC)
32KHZ: R2-PINH1.1, U2.9 (IO1), U3.1 (32KHZ)
DN: D1.5 (I/O2_2), J2.A7, J2.B7
DP: D1.3 (I/O1_2), J2.A6, J2.B6
EPD_3V3: C7.1, EPD_C5.1, J1.15, J1.16, L1.2, Q2.2 (S), TP17.TP
EPD_3V3_C: Q2.1 (G), R_CL1.2, TP13.TP, U2.18 (IO20)
EPD_BUSY: J1.9, TP9.TP, U2.26 (IO3)
EPD_CS: D6.1, J1.12, R9.1, TP10.TP, U2.11 (IO10)
EPD_DC: J1.11, TP11.TP, U2.5 (IO5)
EPD_RST: J1.10, TP12.TP, U2.21 (IO23)
FLASH_CS: D9.1, R5.1, U1.1 (!CS), U2.12 (IO11)
GDR: J1.2, Q3.1 (G), R4.2
GND: BOOT_BUTTON.1, BOOT_BUTTON.2, C1.2, C1_BAT.2, C1_BAT1.2, C1_BAT2.2, C2.2, C2_BAT.2, C3.-, C4_USB.2, C5.2, C5_USB.2, C6.2, C7.2, C8.2, C9.2, C10.2, C10_SUPERCAP.1, CHANGE_BUTTON.1, CHANGE_BUTTON.2, C_DELAY.2, D1.1 (GND), D3.1 (K), D6.2, D8.2, D9.2, D10.2, D11.2, D12.2, EPD_C1.2, EPD_C2.2, EPD_C5.2, EPD_C6.2, EPD_C7.2, EPD_C8.2, EPD_C9.2, EPD_C10.2, EPD_C11.2, EPD_C12.2, IC1.3 (GND), IC4.2 (VSS), J1.8, J1.17, J1.MP1, J1.MP2, J2.A1, J2.A12, J2.B1, J2.B12, J2.MP1, J2.MP2, J2.MP3, J2.MP4, J3.1, J4.G1 (GND_1), J4.G2 (GND_2), J4.G3 (GND_3), J4.G4 (GND_4), J4.P6 (VSS), MCP73831.2 (VSS), R1_PWRUSB.1, R2.1, R2-USB.2, R2-USB1.1, R2_BAT.1, R4.1, RESET_BUTTON.1, RESET_BUTTON.2, SENSOR2.1 (GND), SENSOR2.5 (SDO), SENSOR2.7 (GND), SJ1.1, TP4.TP, TP5.TP, U1.4 (GND), U1.9 (EXP), U2.1 (GND), U2.28 (GND), U2.29_1 (GND), U2.29_2 (GND), U2.29_3 (GND), U2.29_4 (GND), U2.29_5 (GND), U2.29_6 (GND), U2.29_7 (GND), U2.29_8 (GND), U2.29_9 (GND), U3.13 (GND), U4.1 (CTG), U4.4 (GND), U4.6 (QSTRT), U4.9 (EP)
GPIO8: R1.2, U2.10 (IO8)
I2C_PW: C1.1, C2.1, R1_PINH.2, R2_PINH.2, SENSOR2.2 (CSB), SENSOR2.6 (VDDIO), SENSOR2.8 (VDD), U2.17 (IO19)
INT_RTC: R1_PINH1.1, TP15.TP, U2.8 (IO0), U3.3 (SQW/!INT)
IO/BOOT: BOOT_BUTTON.3, BOOT_BUTTON.4, C6.1, R_BOOT.2, U2.15 (IO9)
IO/CHANGE: C10.1, CHANGE_BUTTON.3, CHANGE_BUTTON.4, R_CHANGE.2, U2.23 (IO15)
MISO: D12.1, J4.P7 (DAT0), R8.1, TP6.TP, U1.2 (DO(IO1)), U2.27 (IO2)
MOSI: D11.1, J1.14, J4.P3 (CMD), R7.1, TP7.TP, U1.5 (DI(IO0)), U2.7 (IO7)
unnamed: J2.A5, R2-USB1.2
unnamed: J2.B5, R2-USB.1
unnamed: C4.1, D3.2 (A), D4.1 (K)
unnamed: EPD_C12.1, J1.24
unnamed: EPD_C2.1, J1.5
unnamed: EPD_C10.1, J1.22
unnamed: EPD_C1.1, J1.4
unnamed: EPD_C8.1, J1.20
unnamed: EPD_C6.1, J1.18
unnamed: EPD_C7.1, J1.19
unnamed: D7.1 (CATHODE), R_CAPACITOR.2
unnamed: MCP73831.5 (PROG), R2_BAT.2
unnamed: C1_BAT1.1, D2.1 (CATHODE), IC4.1 (VIN), IC4.3 (CE), Q1.2 (S)
unnamed: CHG_LED.C, R1_BAT.2
unnamed: MCP73831.1 (STAT), R1_BAT.1
unnamed: C_DELAY.1, IC1.5 (CT)
PREVGH: D5.1 (K), EPD_C9.1, J1.21
PREVGL: D4.2 (A), EPD_C11.1, J1.23
RESE: J1.3
RESE': Q3.2 (S), R2.2, R3.1, R3.2, SJ1.2
RESET: C5.1, IC1.1 (VOUT), RESET_BUTTON.3, RESET_BUTTON.4, R_RESET.2, U2.3 (EN)
RTC_RST: U2.16 (IO18), U3.4 (!RST)
RX: TP2.TP, U2.24 (RXD0/GPIO17)
SCK: D10.1, J1.13, J4.P5 (CLK), R6.1, TP8.TP, U1.6 (CLK), U2.6 (IO6)
SCL: J3.4, R2_PINH.1, SENSOR2.4 (SCK), U2.20 (IO22), U3.16 (SCL), U4.7 (SCL)
SDA: J3.3, R1_PINH.1, SENSOR2.3 (SDI), U2.19 (IO21), U3.15 (SDA), U4.8 (SDA)
SRC: C4.2, D5.2 (A), L1.1, Q3.3 (D)
SS_SD: D8.1, J4.P2 (CD/DAT3), R10.1, U2.4 (IO4)
TX: TP1.TP, U2.25 (TXD0/GPIO16)
USB_D+: D1.2 (I/O1_1), U2.14 (IO13)
USB_D-: D1.4 (I/O2_1), U2.13 (IO12)
VBAT: C2_BAT.1, MCP73831.3 (VBAT), Q1.3 (D), TP3.TP, U4.2 (CELL), U4.3 (VDD)
VBUS: C1_BAT.1, C4_USB.1, C5_USB.1, CHG_LED.A, D1.6 (VBUS), D2.2 (ANODE), MCP73831.4 (VIN), Q1.1 (G), R1_PWRUSB.2, TP14.TP
VRTC: C8.1, C10_SUPERCAP.2, R_CAPACITOR.1, U3.14 (VBAT)
VUSB: J2.A4, J2.A9, J2.B4, J2.B9, PFMF.050.1.1

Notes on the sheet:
BME688
USB C connector & ESD protection
Display Type Selector
E-Paper Display Header
RTC Module DS3231SN
E-Paper Drive Circuit
EPD Power
Test Pads
Environmental Sensor BME688
Li-Po Battery Charging Controller
LDO Voltage Regulator
SD Card
ESP32 C6
Voltage Supervisor + Reset & Boot / IO Button
Qwiic / Stemma
SPI ESD Protection Lines
External NOR Flash 64MB
Battery Charge Level

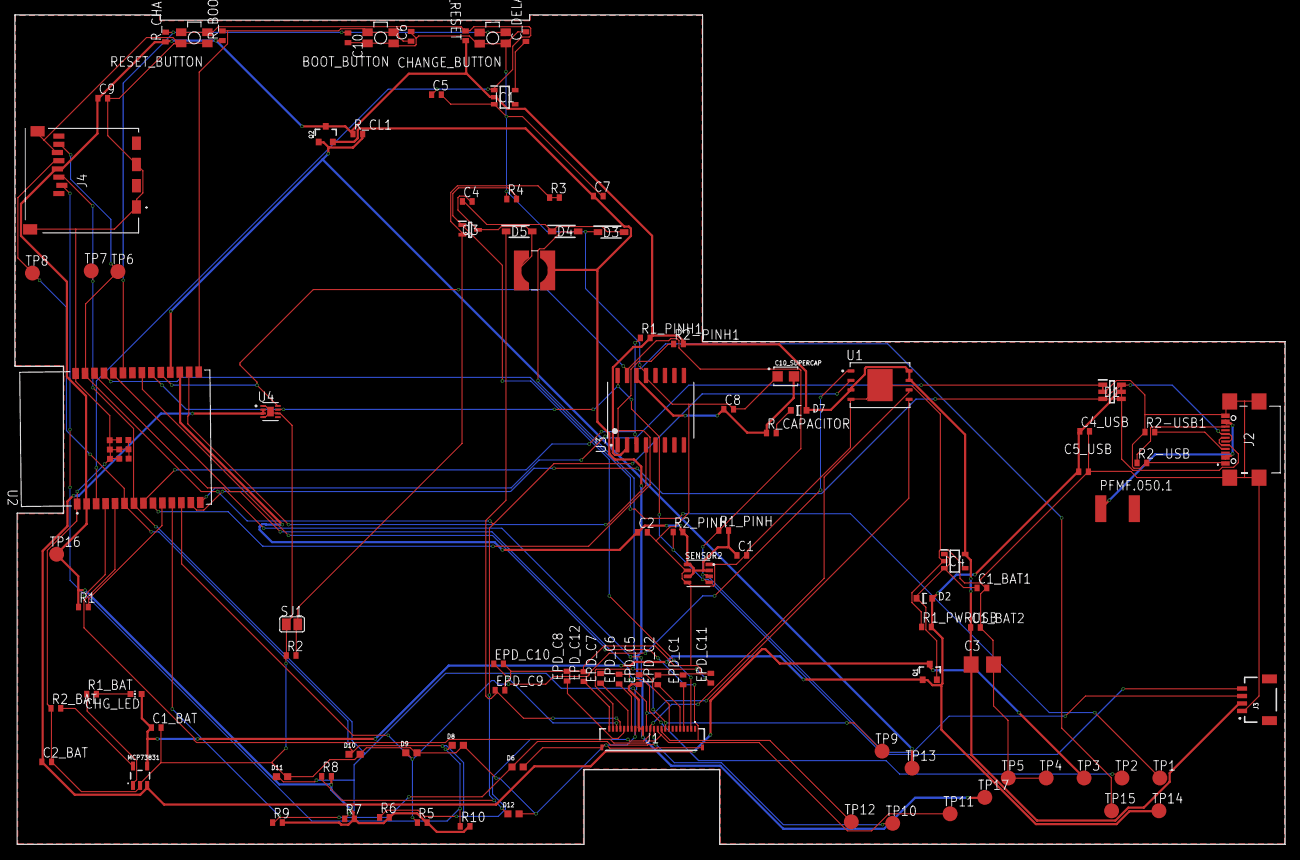
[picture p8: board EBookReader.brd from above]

Board: 2 copper layers, 170.3 x 111.2 mm, 103 parts (0 on the bottom side), 54 nets.

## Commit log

2025-04-05 Add documents
    [EBookReader.brd, EBookReader.sch]
2025-04-15 After review
    [EBookReader_after_review.brd]

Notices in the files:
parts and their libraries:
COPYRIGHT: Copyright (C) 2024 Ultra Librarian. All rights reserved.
